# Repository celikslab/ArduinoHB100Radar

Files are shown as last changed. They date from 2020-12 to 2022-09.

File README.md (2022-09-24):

# ArduinoHB100RadarProject
## HB100 Radar ile Hız Ölçme ve ESP8266 Kullanarak ThingSpeak'e Göndermek

<p align="center">
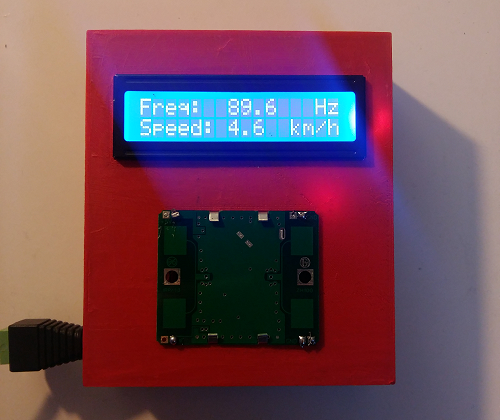
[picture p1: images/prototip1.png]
  
</p>

<br>Bu radar projesinde fiziğin bir kanunu olan Doppler ‘i  kullanarak hareket halindeki araçların hızlarını ölçmek ve bu ölçümleri belli bir yerde toplamaktır. Proje ticari bir fikir olmayıp daha çok belli bir bölgedeki (alandaki) trafik akışını incelemek amacıyla meydana gelmiştir. Bu suretle prototip çalışmasında basit bir radar modülü olan HB100 kullanıldı. Modülün ölçtüğü frekans değerlerini , Doppler formüllerinden yararlanarak hıza geçilmiştir. Çıkan veriler bir lcd ile doğrudan ve de wifi aracılığıyla da uzaktan erişimi sağlanmıştır. Prototip elektronik devre delikli plakete aktarılmış ve de ardından 3d printerdan bir kutu(3d baskı) tasarımı yapılmıştır. Sonuç olarak bu projede Doppler Radar ile hız ölçümlerini site üzerinde görüntüledik.</li>

## Doppler Nedir ?

<br>Doppler etkisi, bir ses kaynağı, bir gözlemciye (yani duyucuya) göre uzaklaşır ya da yakınlaşırsa veya gözlemci, ses kaynağına göre uzaklaşır ya da yakınlaşırsa frekansta ya da ses perdesinde (pitch) meydana gelen belirgin değişikliktir. Doppler frekansı kayma miktarı fD hedef hızının bir ölçütüdür ve tüm dalga hareketlerine uygulanır. Bu etki Avusturyalı fizikçi Christian Doppler (1803-1853) tarafından keşfedilmiş olup, kendisinin adı ile anılmaktadır.

<p align="center">
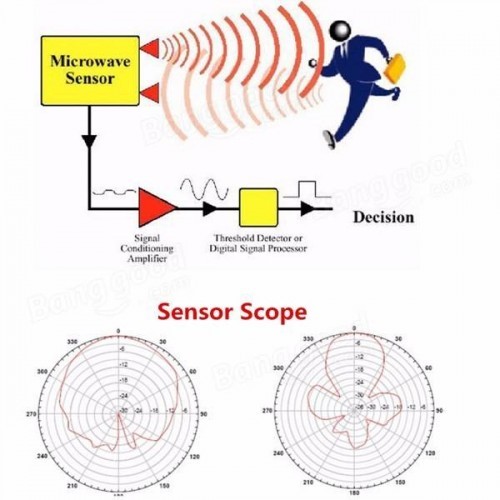
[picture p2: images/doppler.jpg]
  
</p>

## Kullanılan Malzemeler

<li>Arduino pro mini(ch328)</li>
<li>Jumper kablo set</li>    
<li>16x2 lcd ekran</li>      
<li>Hb100 sensör</li>
<li>Esp8266 Wifi Modül</li>
<li>9v adaptor</li>     
<li>güç konnektörü</li>       
<li>delikli plaket</li>
<li>trimpot</li>              

<br>Anfi için malzemeler;

<li>lm324 OpAmp</li>        
<li>2 x 100K, 12K, 330K, 8.2K, 2 x 1M, 2 x 10K direnç</li>    
<li>2 x 2.2nF, 3 x 4.7uF, 0.1uF, 100uF kapasitör</li>

## Devre Şeması

<br>BreadBoard Üzerinde Kurulum ;

<br>Delikli Plaket Üzerinde Kurulum;
<br>
<br>
<p align="center">
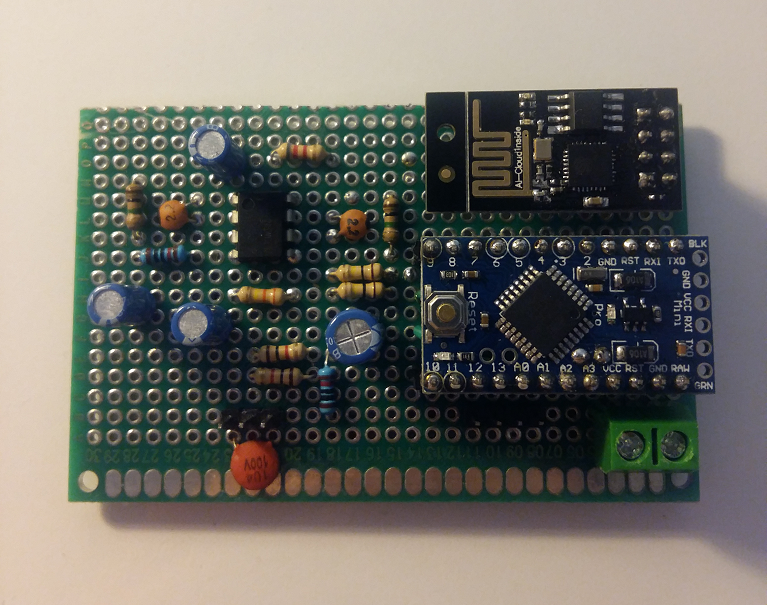
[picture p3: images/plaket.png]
  
</p>

## Kodlar

Kodların tamamına [buradan](https://github.com/mcelik7/ArduinoHB100RadarProject/blob/main/RadarProject.ino) ulaşabilirsiniz.

Bu kısımda modem bilgilerimizi giriyoruz ki wifi modül bağlantı yapabilsin.
```c++
String agAdi = "admin";                 //Modem adını buraya yazıyoruz.    
String agSifresi = "123456";           //Modem şifresini buraya yazıyoruz.
```

Burada ThingSpeak sitesinden aldığımız ApiKeyi yazacağımız satırı görüyoruz.
```c++
String veri = "GET https://api.thingspeak.com/update?api_key=WXQ7CV88VTIPT3XA"; 
//Thingspeak komutu. Key kısmına kendi api keyimizi yazıyoruz.  
```
## Kutu Tasarımı(3D Baskı)

Çizim dosyalarına(stl) [buradan](https://github.com/mcelik7/ArduinoHB100RadarProject/blob/main/stl/) ulaşabilirsiniz.

<p align="center">
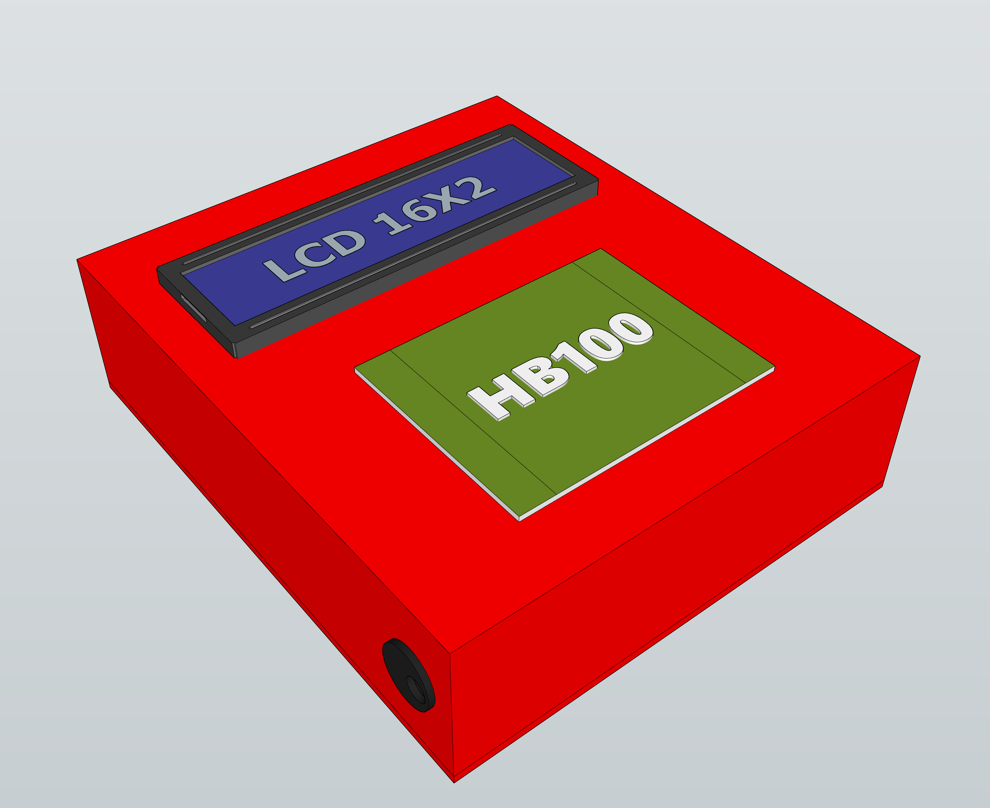
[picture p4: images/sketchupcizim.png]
  
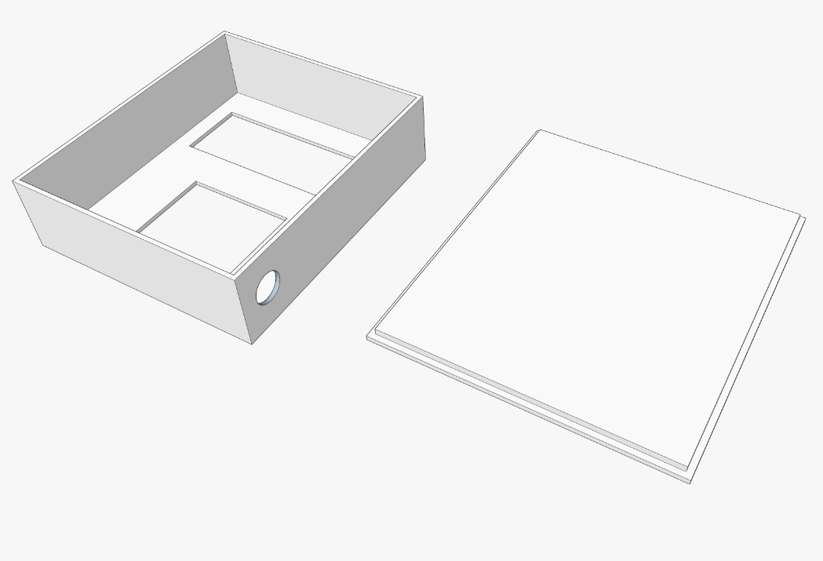
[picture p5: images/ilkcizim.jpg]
    
</p>

## Montaj
<br>

<p align="center">
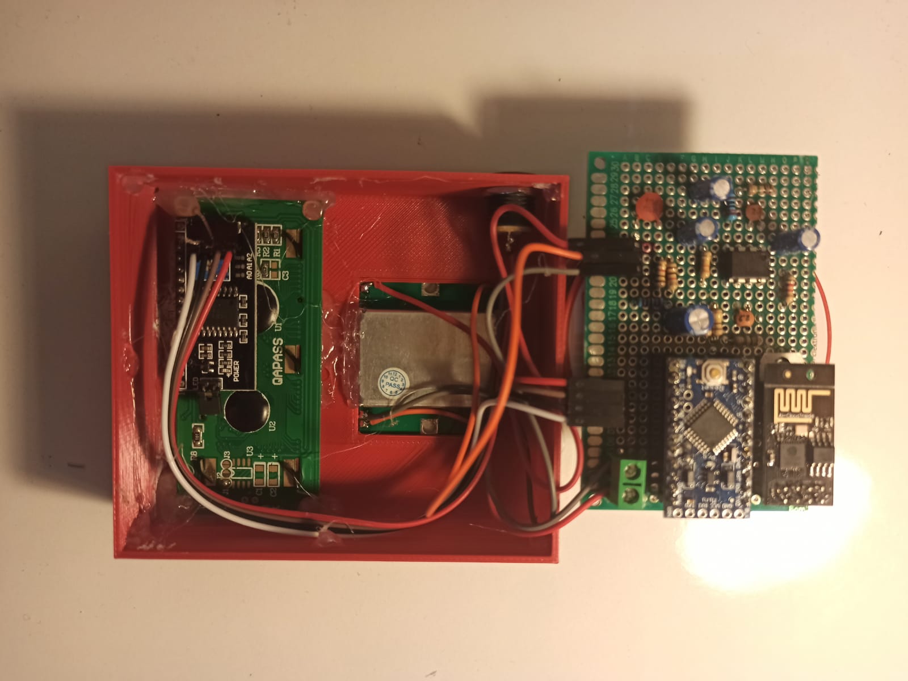
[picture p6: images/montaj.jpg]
  
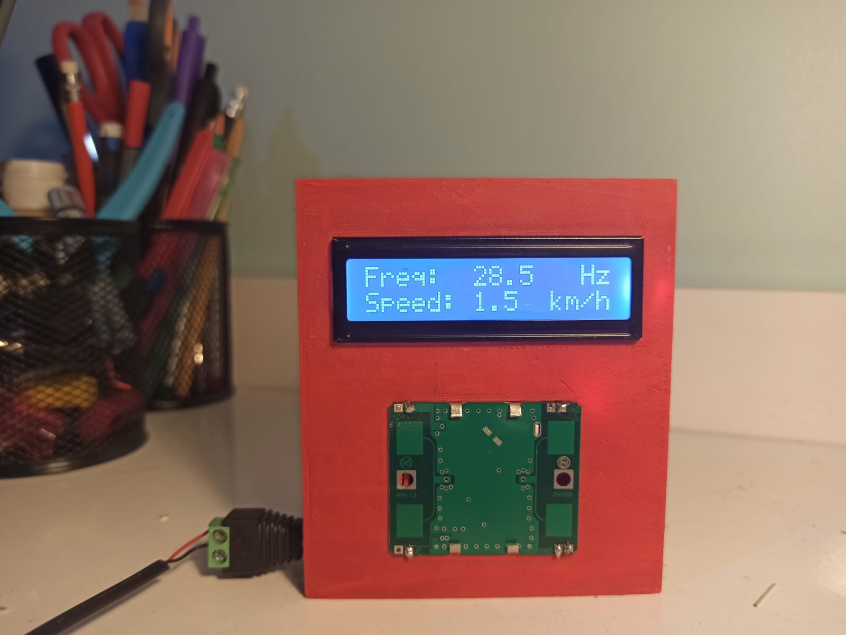
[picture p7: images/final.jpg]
    
</p>

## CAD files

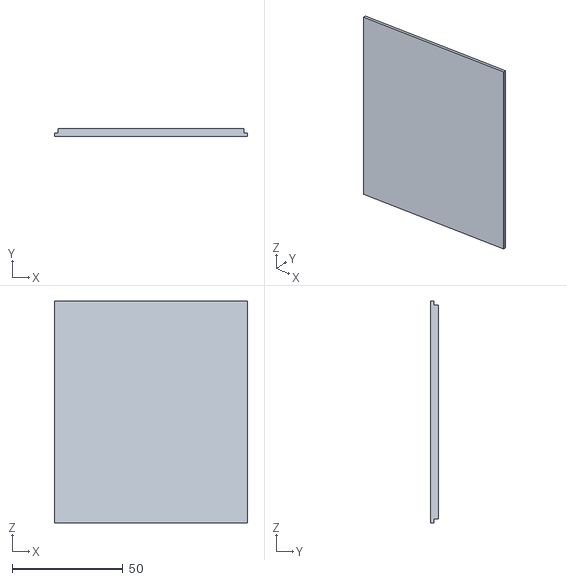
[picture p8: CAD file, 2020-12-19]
stl/kapak.stl
87.0 x 3.50 x 100.0

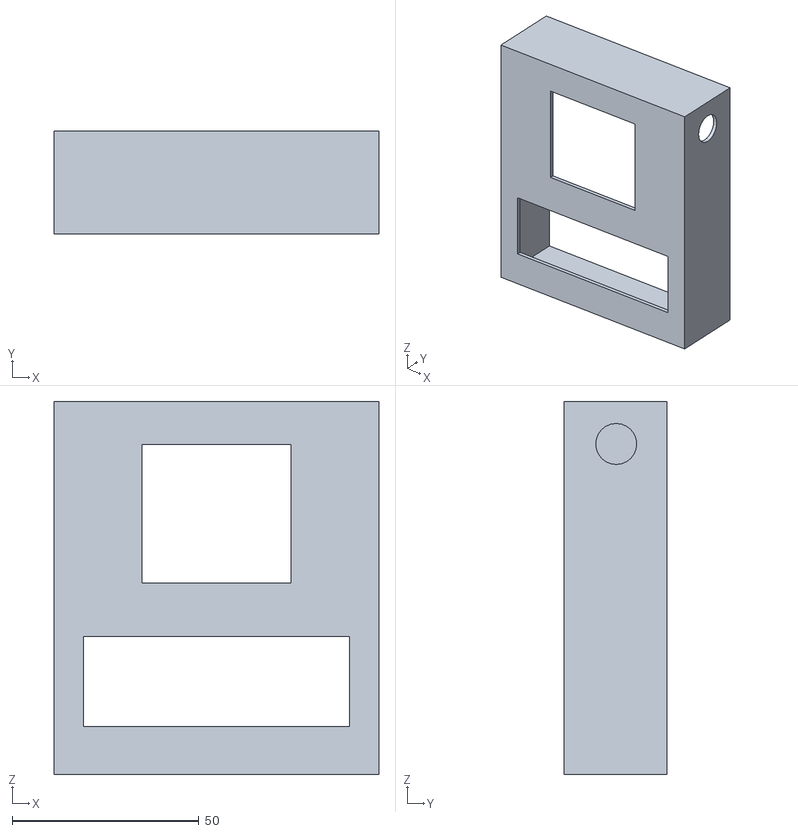
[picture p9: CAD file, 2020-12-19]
stl/gövde.stl
87.0 x 27.5 x 100.0

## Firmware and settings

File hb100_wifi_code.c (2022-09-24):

#include <FreqMeasure.h>
#include <Wire.h> 
#include <LiquidCrystal_I2C.h>
#include<SoftwareSerial.h>   

String agAdi = "Mhmmd";                     //Ağımızın adını buraya yazıyoruz.    
String agSifresi = "123456";                //Ağımızın şifresini buraya yazıyoruz.
String ip = "184.106.153.149";          

int rxPin = 10;                             //ESP8266 RX pini
int txPin = 11;                             //ESP8266 TX pini
LiquidCrystal_I2C lcd(0x27, 16, 2);
SoftwareSerial esp(rxPin, txPin);
 
void setup() {
  lcd.init();
  lcd.backlight();
  lcd.begin(16,2);
  lcd.setCursor(0,0);
  lcd.print("Freq:");
  lcd.setCursor(0,1);
  lcd.print("Speed:");
  FreqMeasure.begin();
  delay(500);


  Serial.begin(9600);                       //Seri port ile haberleşmemizi başlatıyoruz.
  Serial.println("Baslatiliyor");
  esp.begin(115200);                        //ESP8266 ile seri haberleşmeyi başlatıyoruz.
  esp.println("AT");                        //AT komutu ile modül kontrolünü yapıyoruz.
  Serial.println("AT Yollandı");
  while(!esp.find("OK")){                   //Modül hazır olana kadar bekliyoruz.
  esp.println("AT");
  Serial.println("ESP8266 Bulunamadı.");
}
  Serial.println("OK Komutu Alındı");
  esp.println("AT+CWMODE=1");                //ESP8266 modülünü client olarak ayarlıyoruz.
  while(!esp.find("OK")){                    //Ayar yapılana kadar bekliyoruz.
  esp.println("AT+CWMODE=1");
  Serial.println("Ayar Yapılıyor....");
}
  Serial.println("Client olarak ayarlandı");
  Serial.println("Aga Baglaniliyor...");
  esp.println("AT+CWJAP=\""+agAdi+"\",\""+agSifresi+"\"");    //Ağımıza bağlanıyoruz.
  while(!esp.find("OK"));                                     //Ağa bağlanana kadar bekliyoruz.
  Serial.println("Aga Baglandi.");
  delay(1000);
  esp.println("AT+CIPSTART=\"TCP\",\""+ip+"\",80");           //Thingspeak'e bağlanıyoruz.
  if(esp.find("Error")){                                      //Bağlantı hatası kontrolü yapıyoruz.
    Serial.println("AT+CIPSTART Error");
  }      
}

double sum=0;
int count=0;

void loop() {

    if (FreqMeasure.available()) {
    sum = sum + FreqMeasure.read();
    count = count + 1;
                             
    if (count > 30) {
      float frequency = FreqMeasure.countToFrequency(sum / count);
      float spd = frequency / 19.49; 
      lcd.setCursor(7, 0);
      lcd.print("                ");
      lcd.setCursor(7, 1);
      lcd.print("                ");
      lcd.setCursor(7, 0);
      lcd.print(frequency,1);
      Serial.println(spd);
      lcd.setCursor(14, 0);
      lcd.print("Hz");
      //lcd.print("       ");
      lcd.setCursor(7,1);
      lcd.print(spd,1);
      lcd.setCursor(12, 1);
      lcd.print("km/h");
      
 if(spd>8){
        esp.println("AT+CIPSTART=\"TCP\",\""+ip+"\",80");           //Thingspeak'e bağlanıyoruz.
  if(esp.find("Error")){                                      //Bağlantı hatası kontrolü yapıyoruz.
    Serial.println("AT+CIPSTART Error");
  }
      
  String veri = "GET https://api.thingspeak.com/update?api_key=WXQ7CV88VTIPT3XA";   
  //Thingspeak komutu. Key kısmına kendi api keyimizi yazıyoruz.  
  
  veri += "&field1=";
  veri += String(spd);
  veri += "\r\n\r\n"; 
  esp.print("AT+CIPSEND=");                                   //ESP'ye göndereceğimiz veri uzunluğunu veriyoruz.
  esp.println(veri.length()+2);
  delay(1000);
  if(esp.find(">")){                                          //ESP8266 hazır olduğunda içindeki komutlar çalışıyor.
    esp.print(veri);                                          //Veriyi gönderiyoruz.
    Serial.println(veri);
    Serial.println("Veri gonderildi.");
    delay(1000);
  }
   Serial.println("Baglantı Kapatildi.");
  esp.println("AT+CIPCLOSE");                                //Bağlantıyı kapatıyoruz
  delay(200);  
 }
   sum = 0;
      count = 0;
    }
    }                                     
}
